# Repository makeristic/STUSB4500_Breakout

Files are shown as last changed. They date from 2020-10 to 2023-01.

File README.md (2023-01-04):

# STUSB4500_Breakout
USB-PD Breakout Stemma QT board utilising the STUSB4500 chipset.

* Control the STUSB4500 over I2C from any compatible STEMMA/QT board (Adafruit, SparkFun etc.)
* Select the USB C PD power profiles you which (up to three supported?)
* Connect downstream devices to the screw terminals
* View the currently selected voltage from the RGB colour-code.

This work is licensed under a [Creative Commons Attribution 4.0 International License](http://creativecommons.org/licenses/by/4.0/).



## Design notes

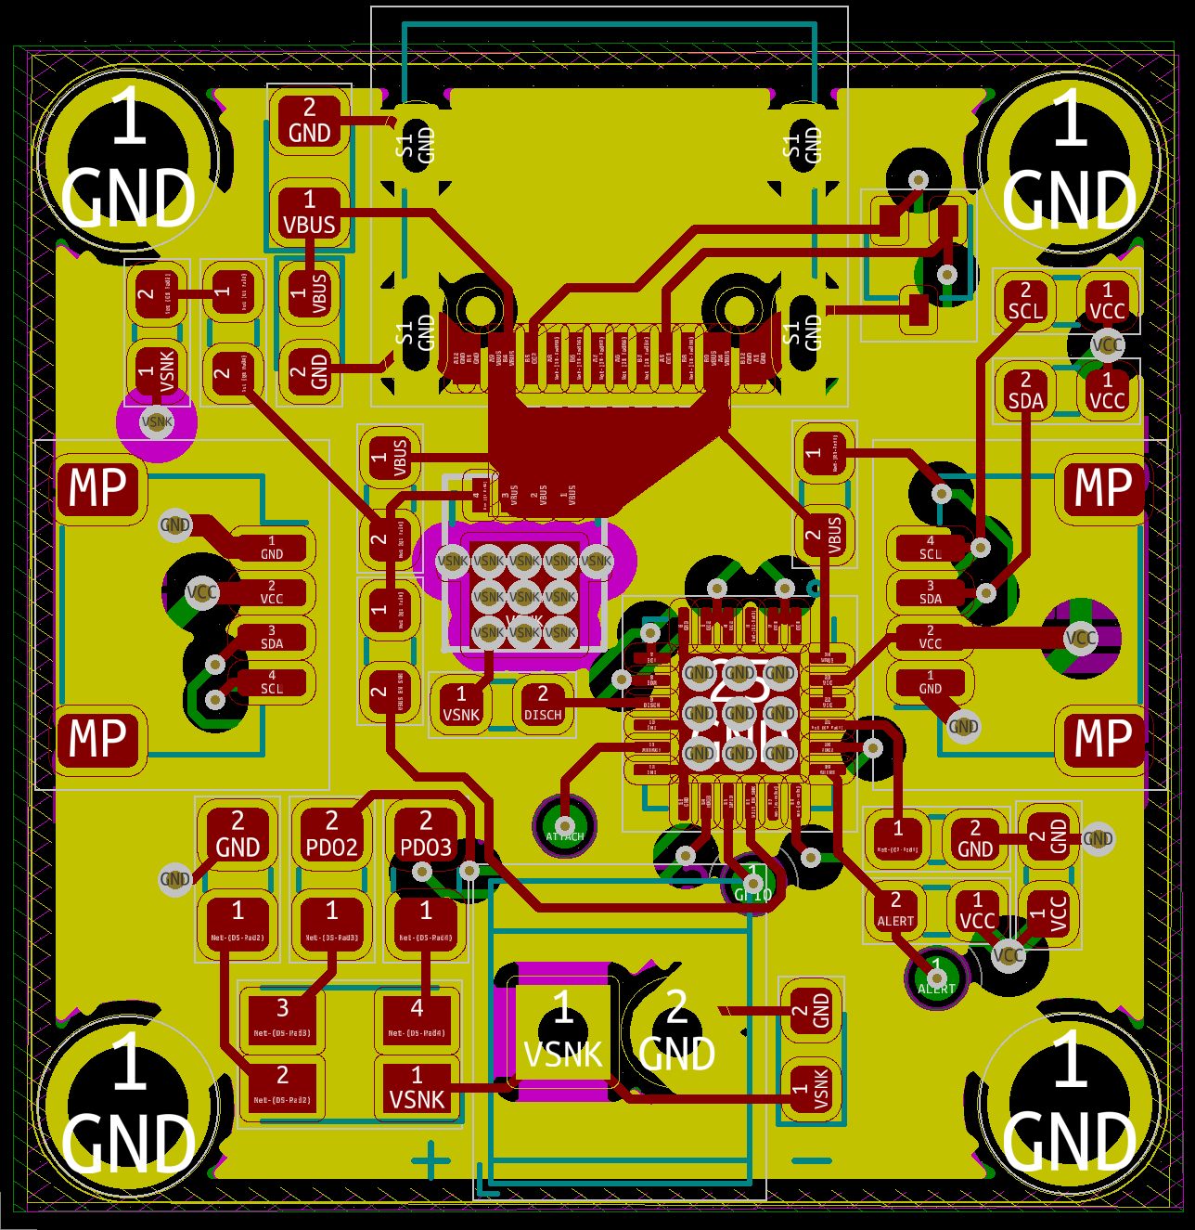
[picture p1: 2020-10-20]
images/pcb1.png

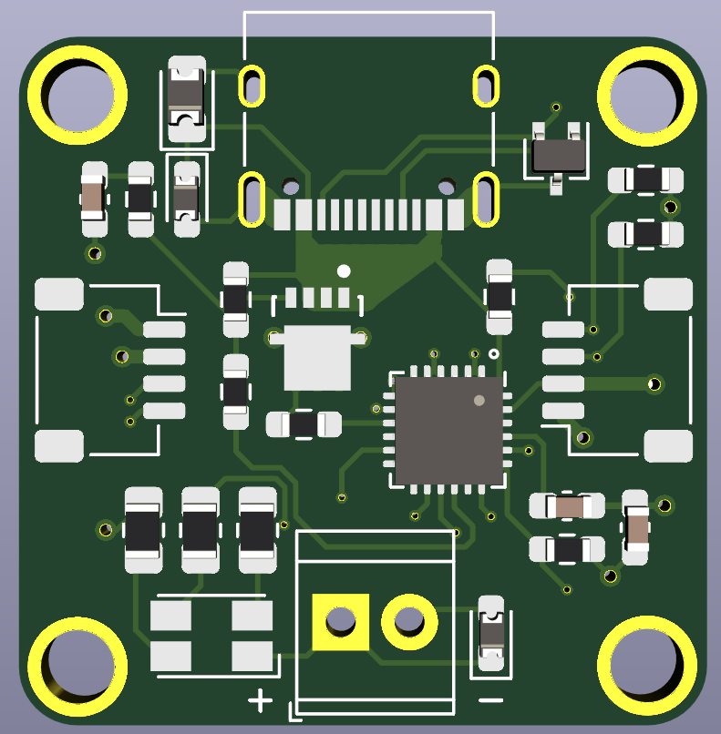
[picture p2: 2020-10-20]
images/3d1.png

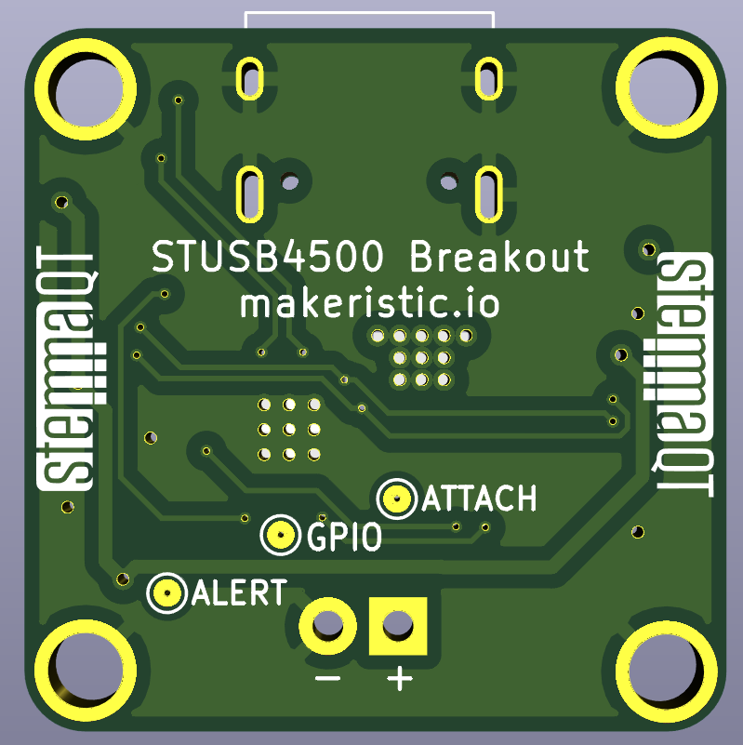
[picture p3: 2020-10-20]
images/3d2.png

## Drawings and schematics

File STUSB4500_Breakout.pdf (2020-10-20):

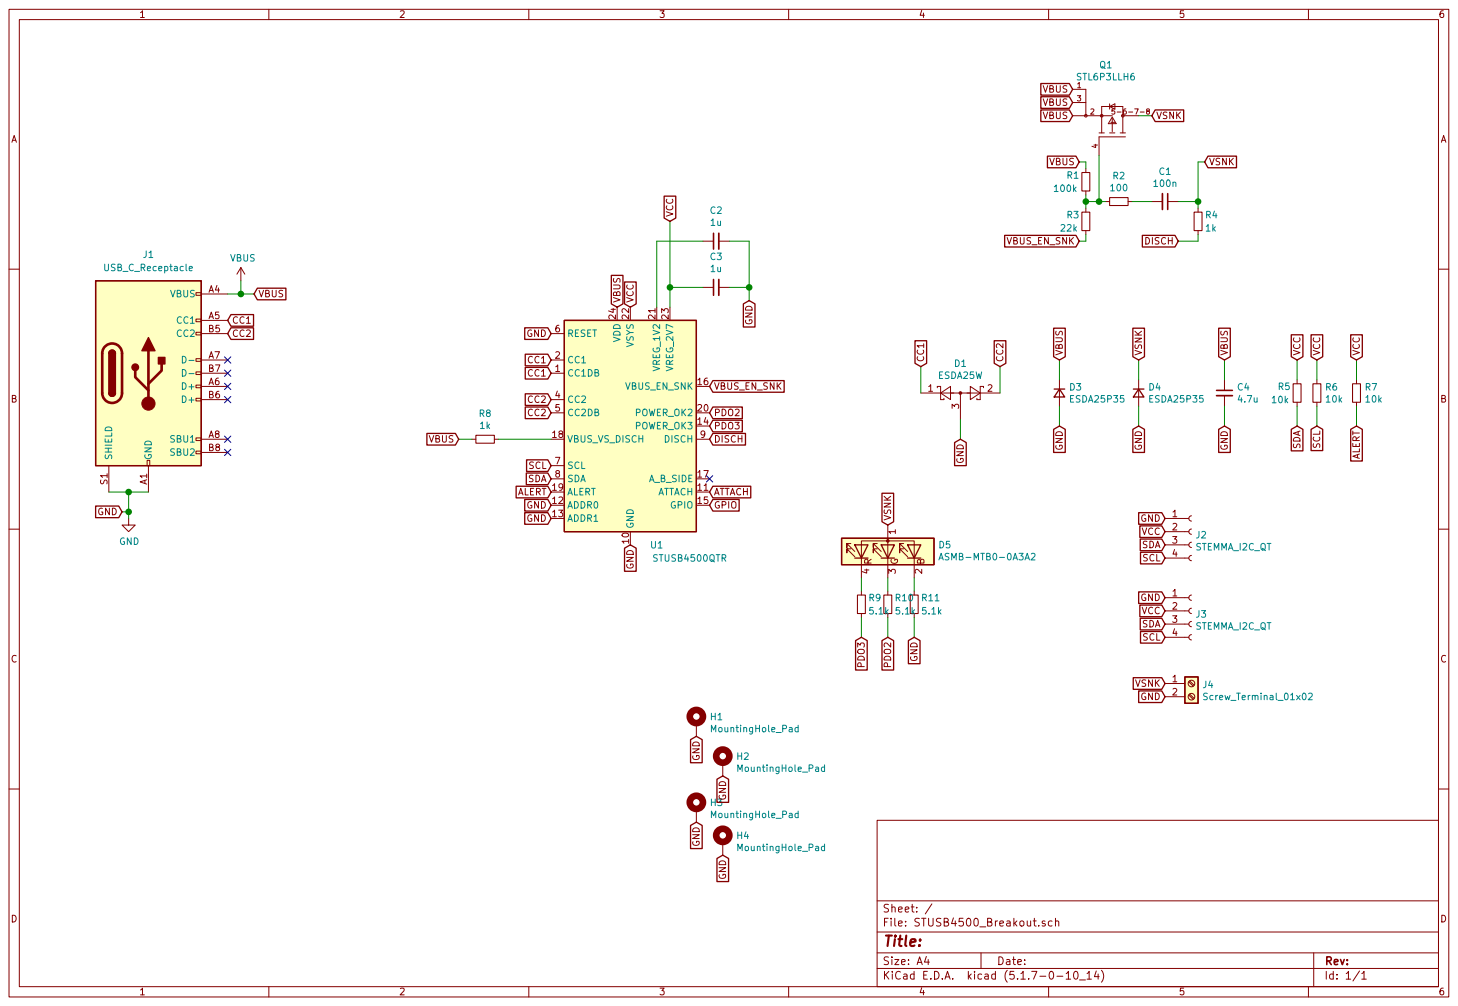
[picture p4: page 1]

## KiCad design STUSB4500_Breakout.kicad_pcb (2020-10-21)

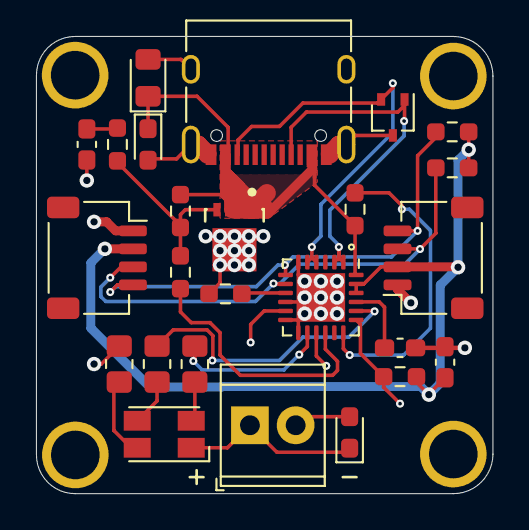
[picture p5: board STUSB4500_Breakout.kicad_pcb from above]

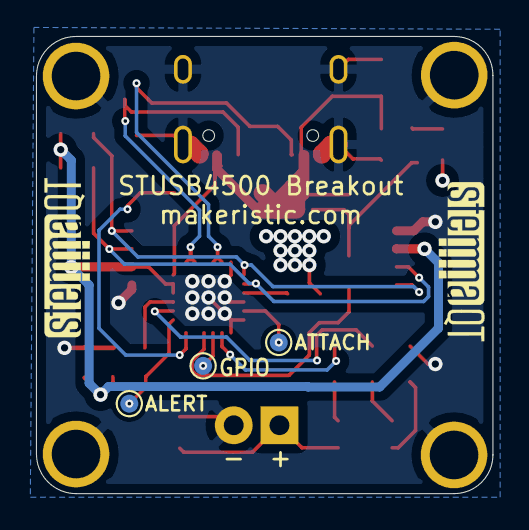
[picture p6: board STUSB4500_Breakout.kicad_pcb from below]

Board: 4 copper layers, 25.4 x 25.4 mm, 32 parts (3 on the bottom side), 22 nets.

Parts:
ALERT: ALERT; TestPoint_Pad_D1.0mm
ATTACH: ATTACH; TestPoint_Pad_D1.0mm
C1: 100n; C_0603_1608Metric_Pad1.08x0.95mm_HandSolder
C2, C3: 1u; C_0603_1608Metric_Pad1.08x0.95mm_HandSolder
C4: 4.7u; D_0805_2012Metric_Pad1.15x1.40mm_HandSolder
D1: ESDA25W; SOT-323_SC-70
D3, D4: ESDA25P35; D_0603_1608Metric_Pad1.05x0.95mm_HandSolder
D5: ASMB-MTB0-0A3A2; LED_Avago_PLCC4_3.2x2.8mm_CW
GPIO: GPIO; TestPoint_Pad_D1.0mm
H1, H2, H3, H4: MountingHole_Pad; MountingHole_2.7mm_M2.5_Pad_Small
J1: USB_C_Receptacle; USB_C_Receptacle_XKB_U262-16XN-4BVC11
J2, J3: STEMMA_I2C_QT; JST_SH_SM04B-SRSS-TB_1x04-1MP_P1.00mm_Horizontal
J4: Screw_Terminal_01x02; TerminalBlock_TE_282834-2_1x02_P2.54mm_Horizontal
Q1: STL6P3LLH6
R1: 100k; R_0603_1608Metric_Pad0.98x0.95mm_HandSolder
R2: 100; R_0603_1608Metric_Pad0.98x0.95mm_HandSolder
R3: 22k; R_0603_1608Metric_Pad0.98x0.95mm_HandSolder
R4, R8: 1k; R_0603_1608Metric_Pad0.98x0.95mm_HandSolder
R5, R6, R7: 10k; R_0603_1608Metric_Pad0.98x0.95mm_HandSolder
R9, R10, R11: 5.1k; R_0805_2012Metric_Pad1.20x1.40mm_HandSolder
U1: STUSB4500QTR; QFN-24-1EP_4x4mm_P0.5mm_EP2.7x2.7mm

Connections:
ALERT: ALERT.1, R7.2, U1.19
ATTACH: ATTACH.1, U1.11
CC1: D1.1, J1.A5, U1.1, U1.2
CC2: D1.2, J1.B5, U1.4, U1.5
DISCH: R4.2, U1.9
GND: C2.2, C3.2, C4.2, D1.3, D3.2, D4.2, H1.1, H2.1, H3.1, H4.1, J1.A1, J1.A12, J1.B1, J1.B12, J1.S1, J2.1, J3.1, J4.2, R11.2, U1.6, U1.10, U1.12, U1.13, U1.25
GPIO: GPIO.1, U1.15
unnamed: C1.2, R2.1
unnamed: C2.1, U1.21
unnamed: D5.2, R11.1
unnamed: D5.3, R10.1
unnamed: D5.4, R9.1
unnamed: Q1.4, R1.2, R2.2, R3.1
unnamed: R8.1, U1.18
PDO2: R10.2, U1.20
PDO3: R9.2, U1.14
SCL: J2.4, J3.4, R6.2, U1.7
SDA: J2.3, J3.3, R5.2, U1.8
VBUS: C4.1, D3.1, J1.A4, J1.A9, J1.B4, J1.B9, Q1.1, Q1.2, Q1.3, R1.1, R8.2, U1.24
VBUS_EN_SNK: R3.2, U1.16
VCC: C3.1, J2.2, J3.2, R5.1, R6.1, R7.1, U1.22, U1.23
VSNK: C1.1, D4.1, D5.1, J4.1, Q1.5-6-7-8, R4.1

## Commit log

2020-10-20 Updated routing as suggested my Mark Olsson @k0d
    [STUSB4500_Breakout.kicad_pcb]
2020-10-20 Updated ready for manufacturing
    [STUSB4500_Breakout-B_Cu.gbr, STUSB4500_Breakout-B_Mask.gbr, STUSB4500_Breakout-B_Paste.gbr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]
2026-10-26 fix: restore STUSB4500 sources and flag power defects (#1)
    * docs: improve project discovery and reuse guidance
    Describe the historical design and available artifacts from repository evidence. Keep hardware and fabrication outputs unchanged, preserve third-party rights, and make unresolved setup and validation limits visible.
    * docs: record completed discoverability delivery
    * fix: restore STUSB4500 dependencies and reconcile its netlist
    Restore exact historical symbols rather than substituting modern pin geometry. Reconcile only headers proven absent from the current schematic, preserve the legacy format, and document the regulator and RGB voltage-domain defects instead of applying spec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

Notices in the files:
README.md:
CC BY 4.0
